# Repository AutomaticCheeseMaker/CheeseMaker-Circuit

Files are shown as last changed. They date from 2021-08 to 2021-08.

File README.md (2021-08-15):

# CheeseMaker-Circuit

This is the circuit board for the hardware that controls the stirring machine. On top of this circuit you'll need:

- A stepper driver, e.g. A4988
- 1-2 DS18B20 Temperature Sensors
- SSR for switching on Water Heater (Kettle Element)
- Arduino Mega 2560
- 3x 4.7 kohm resistors
- LM2596 DC to DC Buck Converter (Convert input voltage to 5V)
- Connectors (or plain pin headers) - I used JST-XH socket for the stepper output, KF2510 for the temp sensor input

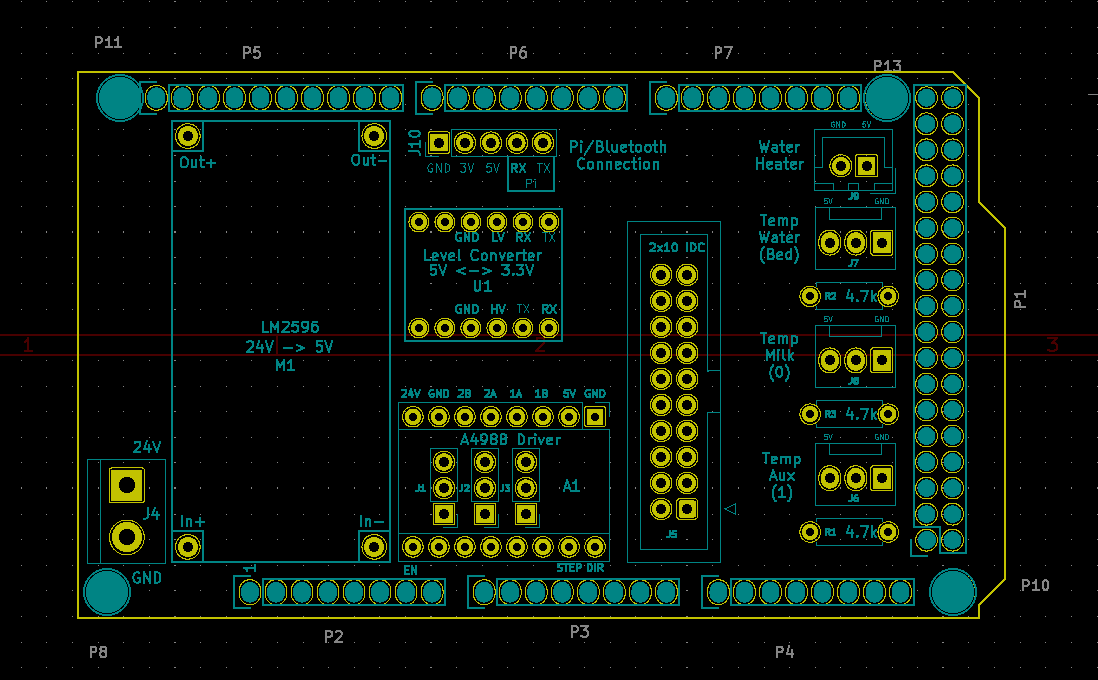
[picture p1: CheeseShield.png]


Notes:

- The schematics assume 24V input. This is because my stepper was 24V. Note that Arduino Mega 2560 isn't 24V tolerant which is why the LM2596 is required.

## CheeseDistribution
To reduce the jitter on the servos this second circuit was developed to sit on the stirrer arm servo and distribute all the connections out to the stepper and servo.

The connection between this board and the main one is via a 20 pin IDC cable.

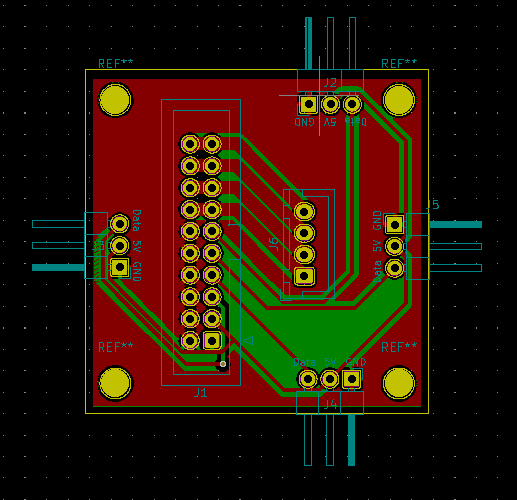
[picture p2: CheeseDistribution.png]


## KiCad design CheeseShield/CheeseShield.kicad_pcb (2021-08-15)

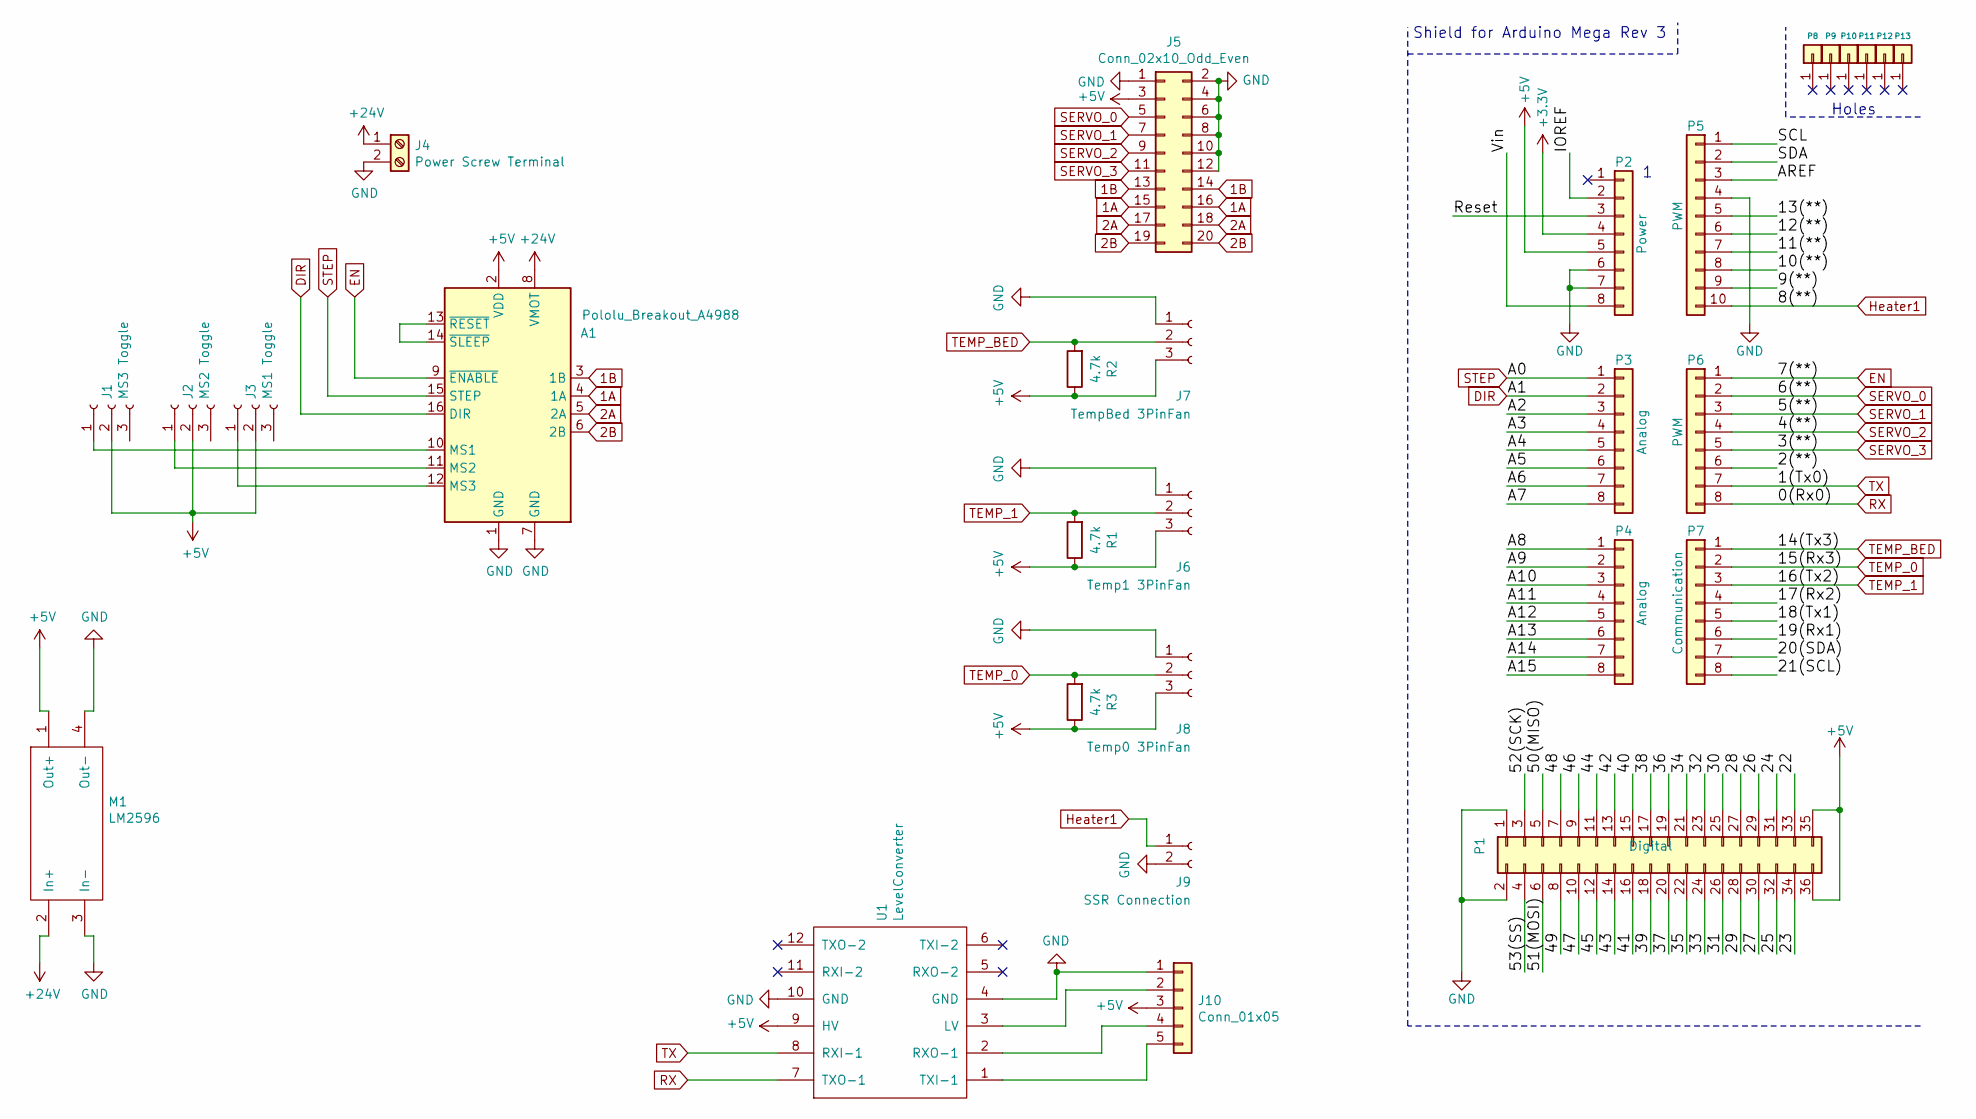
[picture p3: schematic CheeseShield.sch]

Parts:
A1: Pololu_Breakout_A4988; Pololu_Breakout-16_15.2x20.3mm
J1: MS3 Toggle; Pin_Header_Straight_1x03_Pitch2.54mm
J2: MS2 Toggle; Pin_Header_Straight_1x03_Pitch2.54mm
J3: MS1 Toggle; Pin_Header_Straight_1x03_Pitch2.54mm
J4: Power Screw Terminal; TerminalBlock_bornier-2_P5.08mm
J5: Conn_02x10_Odd_Even; IDC-Header_2x10_P2.54mm_Vertical
J6: Temp1 3PinFan; Fan_Pin_Header_Straight_1x03
J7: TempBed 3PinFan; Fan_Pin_Header_Straight_1x03
J8: Temp0 3PinFan; Fan_Pin_Header_Straight_1x03
J9: SSR Connection; JST_XH_B02B-XH-A_02x2.50mm_Straight
J10: Conn_01x05; PinHeader_1x05_P2.54mm_Vertical
M1: LM2596
P1: Digital; Socket_Strip_Arduino_2x18
P2: Power; Socket_Strip_Arduino_1x08
P3, P4: Analog; Socket_Strip_Arduino_1x08
P5: PWM; Socket_Strip_Arduino_1x10
P6: PWM; Socket_Strip_Arduino_1x08
P7: Communication; Socket_Strip_Arduino_1x08
P8, P9, P10, P11, P12, P13: CONN_01X01; Arduino_1pin
R1, R2, R3: 4.7k; R_Axial_DIN0207_L6.3mm_D2.5mm_P7.62mm_Horizontal
U1: LevelConverter

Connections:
1A: A1.4 (1A), J5.15, J5.16
1B: A1.3 (1B), J5.13, J5.14
2A: A1.5 (2A), J5.17, J5.18
2B: A1.6 (2B), J5.19, J5.20
+3V3: P2.4
+5V: A1.2 (VDD), J1.2, J2.2, J3.2, J5.3, J6.3, J7.3, J8.3, J10.3, M1.1 (Out+), P1.35, P1.36, P2.5, R1.1, R2.1, R3.1, U1.9 (HV)
+24V: A1.8 (VMOT), J4.1, M1.2 (In+)
/2(**): P6.6
/9(**): P5.9
/10(**): P5.8
/11(**): P5.7
/12(**): P5.6
/13(**): P5.5
/17(Rx2): P7.4
/18(Tx1): P7.5
/19(Rx1): P7.6
/20(SDA): P7.7
/21(SCL): P7.8
/22: P1.33
/23: P1.34
/24: P1.31
/25: P1.32
/26: P1.29
/27: P1.30
/28: P1.27
/29: P1.28
/30: P1.25
/31: P1.26
/32: P1.23
/33: P1.24
/34: P1.21
/35: P1.22
/36: P1.19
/37: P1.20
/38: P1.17
/39: P1.18
/40: P1.15
/41: P1.16
/42: P1.13
/43: P1.14
/44: P1.11
/45: P1.12
/46: P1.9
/47: P1.10
/48: P1.7
/49: P1.8
/50(MISO): P1.5
/51(MOSI): P1.6
/52(SCK): P1.3
/53(SS): P1.4
/A2: P3.3
/A3: P3.4
/A4: P3.5
/A5: P3.6
/A6: P3.7
/A7: P3.8
/A8: P4.1
/A9: P4.2
/A10: P4.3
/A11: P4.4
/A12: P4.5
/A13: P4.6
/A14: P4.7
/A15: P4.8
/AREF: P5.3
/IOREF: P2.2
/Reset: P2.3
/SCL: P5.1
/SDA: P5.2
/Vin: P2.8
DIR: A1.16 (DIR), P3.2
EN: A1.9 (~ENABLE), P6.1
GND: A1.1 (GND), A1.7 (GND), J4.2, J5.1, J5.2, J5.4, J5.6, J5.8, J5.10, J5.12, J6.1, J7.1, J8.1, J9.2, J10.1, M1.3 (In-), M1.4 (Out-), P1.1, P1.2, P2.6, P2.7, P5.4, U1.4 (GND), U1.10 (GND)
Heater1: J9.1, P5.10
unnamed: A1.10 (MS1), J1.1
unnamed: A1.11 (MS2), J2.1
unnamed: A1.12 (MS3), J3.1
unnamed: A1.13 (~RESET), A1.14 (~SLEEP)
unnamed: J10.2, U1.3 (LV)
unnamed: J10.4, U1.2 (RXO-1)
unnamed: J10.5, U1.1 (TXI-1)
RX: P6.8, U1.7 (TXO-1)
SERVO_0: J5.5, P6.2
SERVO_1: J5.7, P6.3
SERVO_2: J5.9, P6.4
SERVO_3: J5.11, P6.5
STEP: A1.15 (STEP), P3.1
TEMP_0: J8.2, P7.2, R3.2
TEMP_1: J6.2, P7.3, R1.2
TEMP_BED: J7.2, P7.1, R2.2
TX: P6.7, U1.8 (RXI-1)

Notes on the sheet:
Shield for Arduino Mega Rev 3
Holes

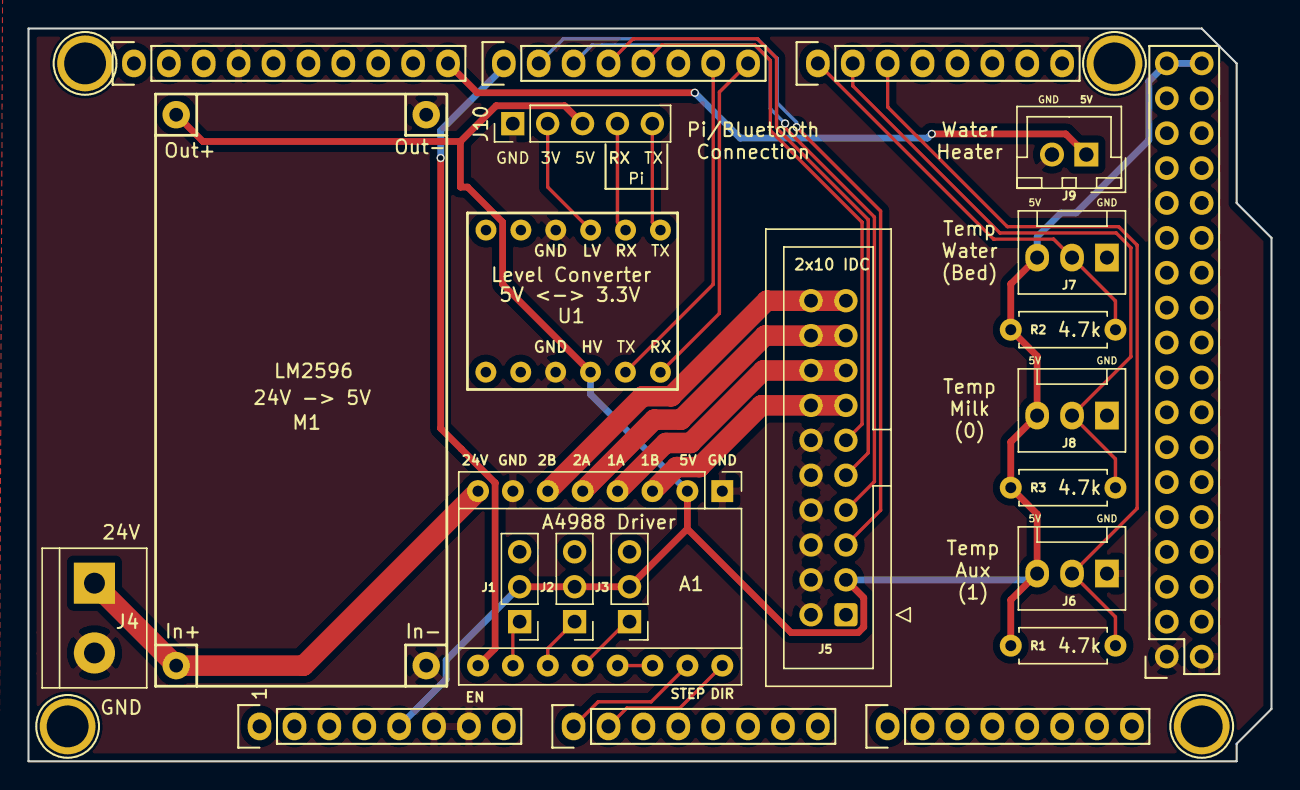
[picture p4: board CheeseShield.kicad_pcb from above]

Board: 2 copper layers, 90.5 x 53.3 mm, 27 parts (0 on the bottom side), 27 nets.

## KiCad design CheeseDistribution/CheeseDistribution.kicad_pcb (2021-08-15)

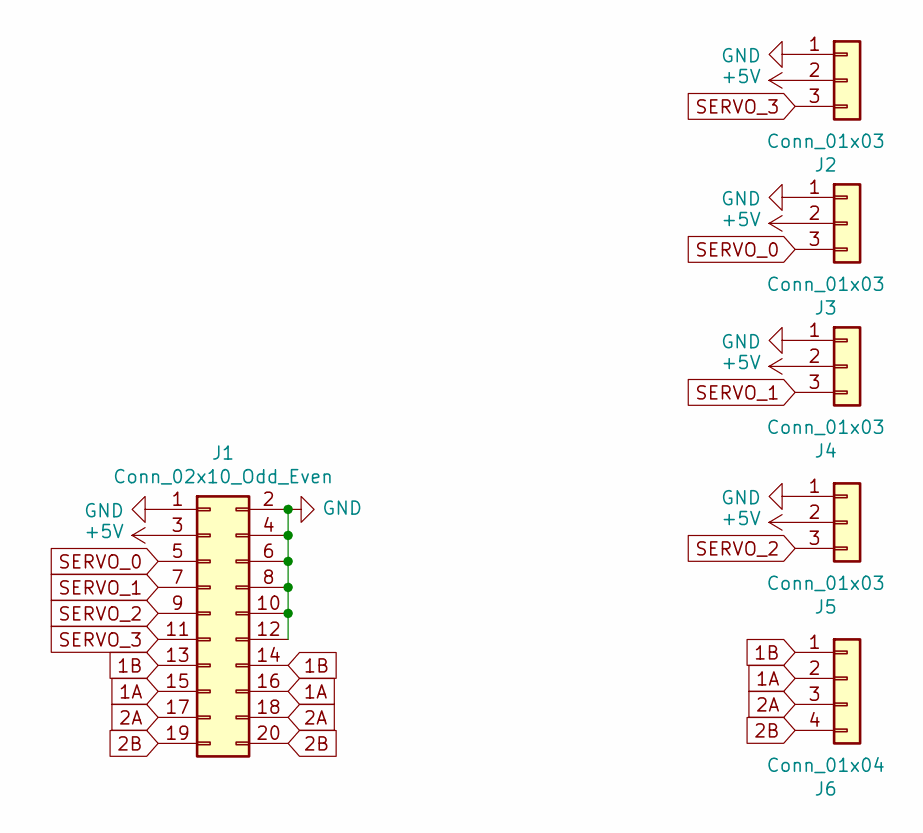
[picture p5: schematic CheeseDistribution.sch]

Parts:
J1: Conn_02x10_Odd_Even; IDC-Header_2x10_P2.54mm_Vertical
J2, J3, J4, J5: Conn_01x03; PinHeader_1x03_P2.54mm_Horizontal
J6: Conn_01x04; JST_XH_B4B-XH-A_1x04_P2.50mm_Vertical

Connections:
1A: J1.15, J1.16, J6.2
1B: J1.13, J1.14, J6.1
2A: J1.17, J1.18, J6.3
2B: J1.19, J1.20, J6.4
+5V: J1.3, J2.2, J3.2, J4.2, J5.2
GND: J1.1, J1.2, J1.4, J1.6, J1.8, J1.10, J1.12, J2.1, J3.1, J4.1, J5.1
SERVO_0: J1.5, J3.3
SERVO_1: J1.7, J4.3
SERVO_2: J1.9, J5.3
SERVO_3: J1.11, J2.3

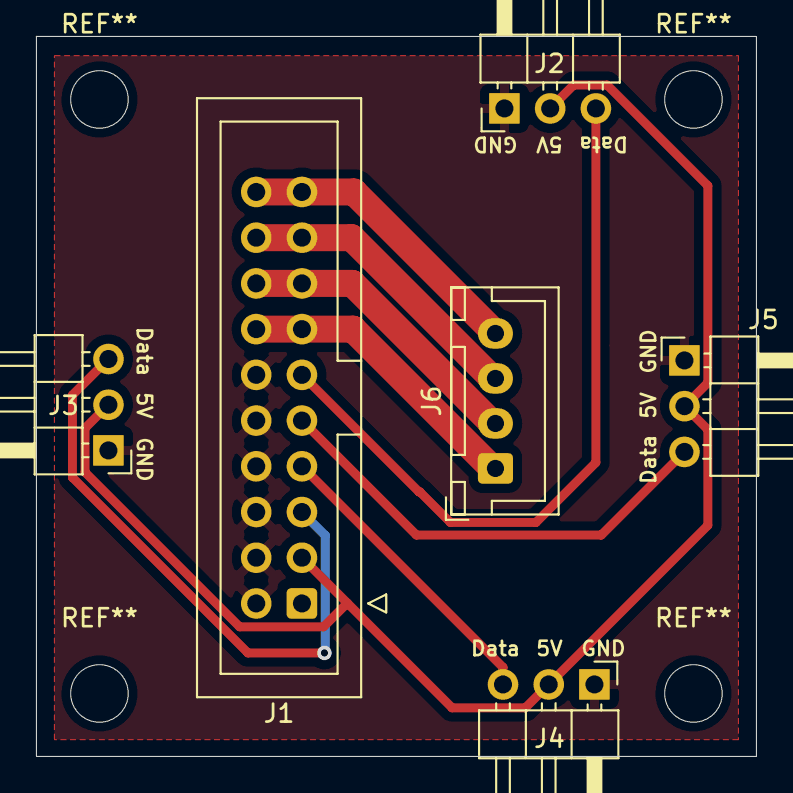
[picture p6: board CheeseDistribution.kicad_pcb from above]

Board: 2 copper layers, 40.0 x 40.0 mm, 6 parts (0 on the bottom side), 10 nets.

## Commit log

2019-12-09 Initial commit of board schematic
    [CheeseShield.kicad_pcb, CheeseShield.sch, CheeseShield_Bak.kicad_pcb]
2020-01-31 feat: Added in bluetooth and servo headers
    [CheeseShield.kicad_pcb, CheeseShield.sch]
2021-08-15 feat: updated circuit to minimize servo jitter
    [CheeseDistribution-B_Cu.gbr, CheeseDistribution-B_Mask.gbr, CheeseDistribution-B_Paste.gbr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]
